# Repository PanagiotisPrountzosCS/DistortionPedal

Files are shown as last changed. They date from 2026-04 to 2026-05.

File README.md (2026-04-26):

# Custom distortion pedal implemented in kicad and ltspice

## This pedal is comprised of 3 stages:
  - Amplification
  - Clipping
  - Output Filtering

## The main branch contains a 100mm X 100mm PCB, while the 1590b-pcb branch contains a 35mm X 88mm PCB, which fits inside a 1590b box

## 1590b pcb


## 100mmx100mm pcb


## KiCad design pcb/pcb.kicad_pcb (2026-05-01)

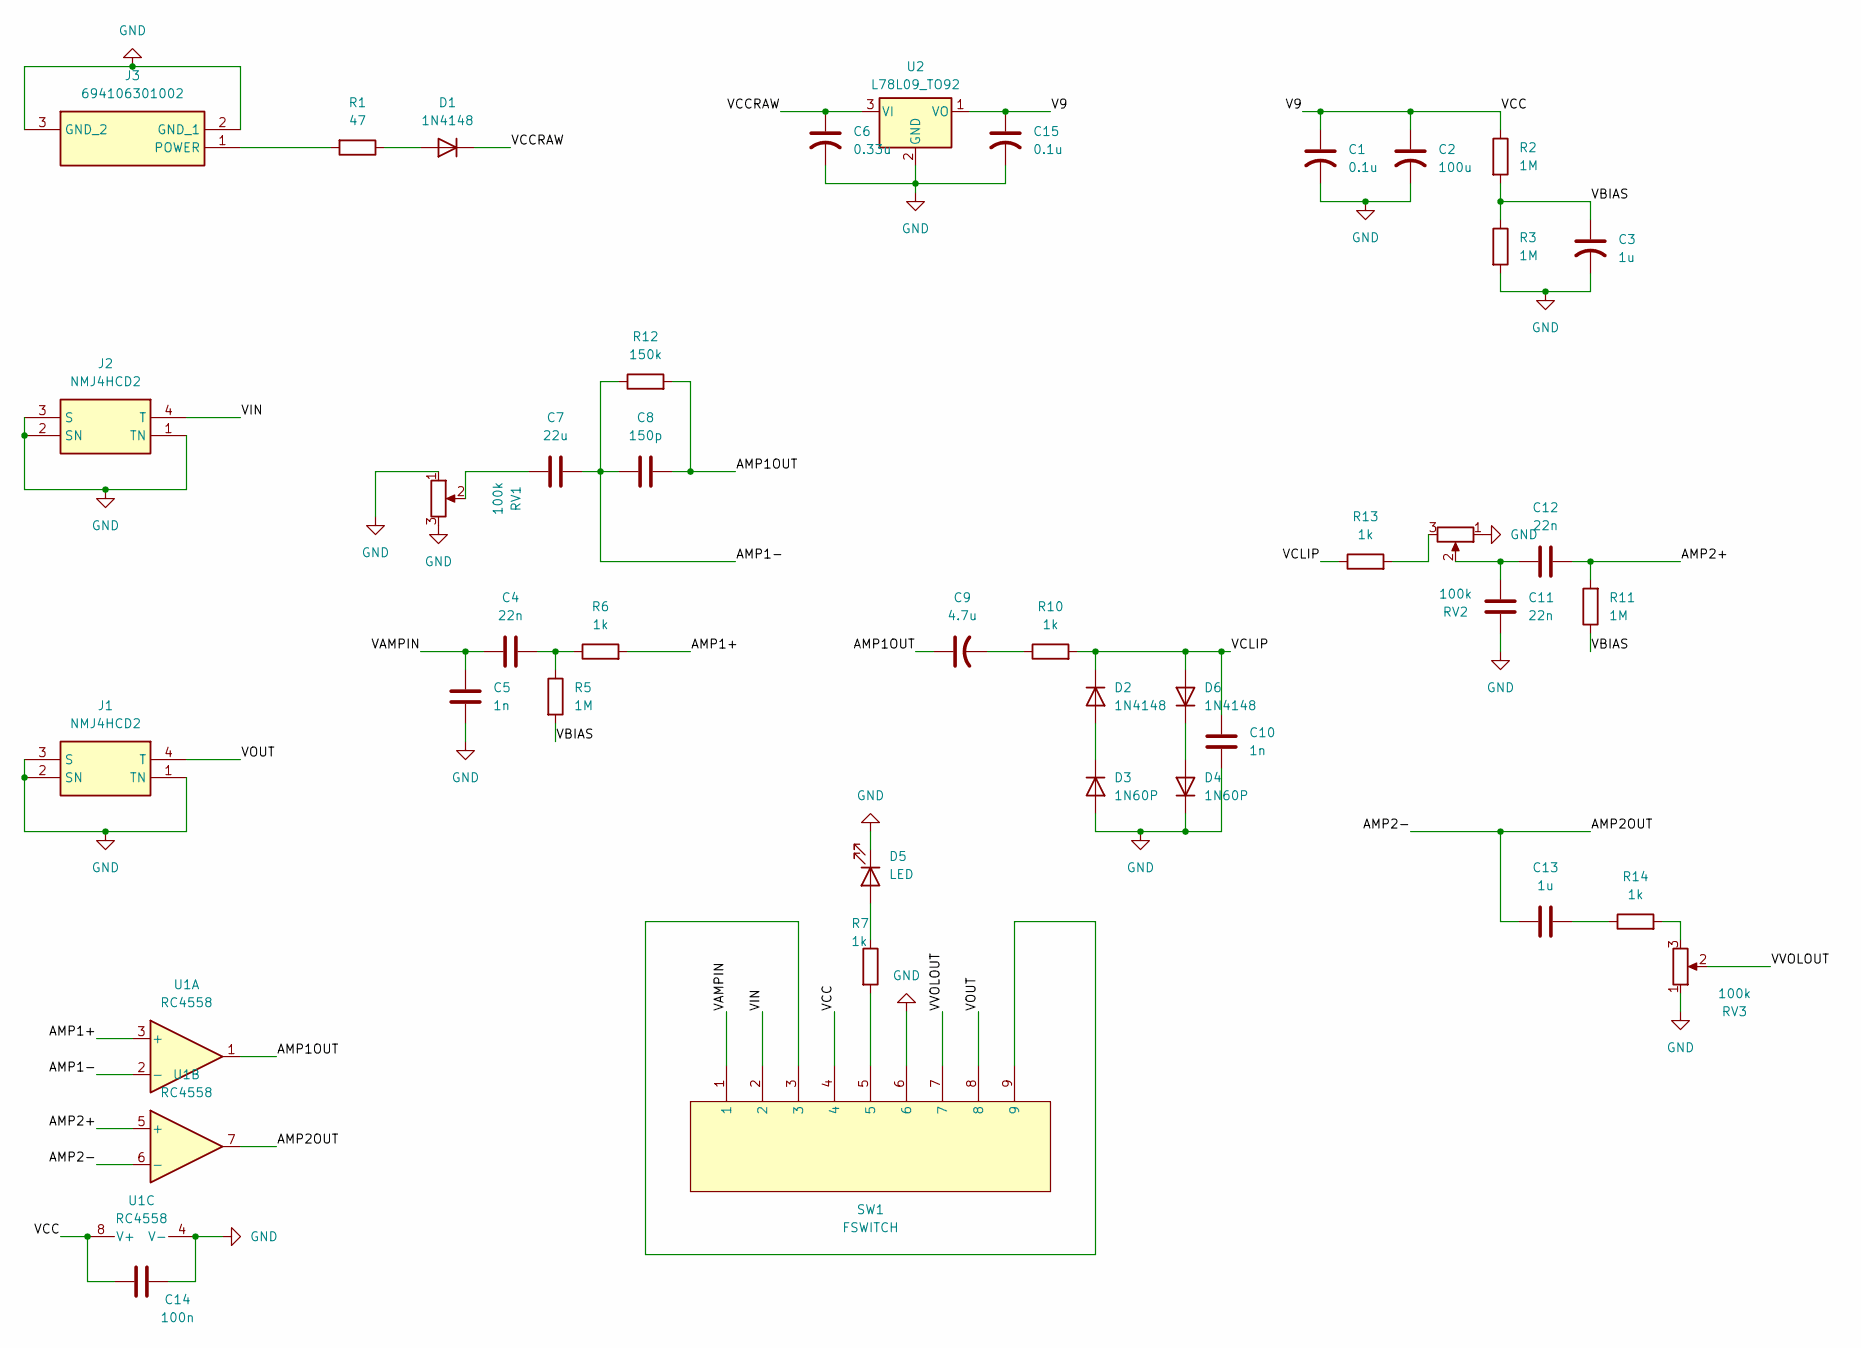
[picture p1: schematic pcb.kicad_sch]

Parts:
C1, C15: 0.1u; C_Radial_D5.0mm_H11.0mm_P2.00mm
C2: 100u; C_Radial_D6.3mm_H11.0mm_P2.50mm
C3: 1u; C_Radial_D6.3mm_H11.0mm_P2.50mm
C4, C12: 22n; C_Rect_L7.2mm_W2.5mm_P5.00mm
C5, C10: 1n; C_Disc_D3.0mm_W1.6mm_P2.50mm
C6: 0.33u; C_Radial_D5.0mm_H11.0mm_P2.00mm
C7: 22u; C_Radial_D5.0mm_H11.0mm_P2.00mm
C8: 150p; C_Disc_D3.0mm_W1.6mm_P2.50mm
C9: 4.7u; C_Radial_D5.0mm_H11.0mm_P2.00mm
C11: 22n; C_Disc_D3.0mm_W1.6mm_P2.50mm
C13: 1u; C_Rect_L7.2mm_W2.5mm_P5.00mm
C14: 100n; C_Disc_D3.0mm_W1.6mm_P2.50mm
D1, D2, D6: 1N4148; D_DO-35_SOD27_P7.62mm_Horizontal
D3, D4: 1N60P; D_DO-41_SOD81_P10.16mm_Horizontal
D5: LED; LED_D3.0mm
J1, J2: NMJ4HCD2; Mouser Part Number 550-12202
J3: 694106301002; Mouser Part Number 710-694106301002
R1: 47; R_Axial_DIN0207_L6.3mm_D2.5mm_P10.16mm_Horizontal
R2, R3, R5, R11: 1M; R_Axial_DIN0207_L6.3mm_D2.5mm_P10.16mm_Horizontal
R6, R7, R10, R13, R14: 1k; R_Axial_DIN0207_L6.3mm_D2.5mm_P10.16mm_Horizontal
R12: 150k; R_Axial_DIN0207_L6.3mm_D2.5mm_P10.16mm_Horizontal
RV1, RV2, RV3: 100k; Potentiometer_Omeg_PC16BU_Vertical
SW1: FSWITCH; 3PDT
U1: RC4558; CERDIP-8_W7.62mm_SideBrazed_LongPads_Socket
U2: L78L09_TO92; TO-92_Inline

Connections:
/AMP1+: R6.2, U1.3 (+)
/AMP1-: C7.2, C8.1, R12.1, U1.2 (-)
/AMP1OUT: C8.2, C9.1, R12.2, U1.1
/AMP2+: C12.2, R11.2, U1.5 (+)
/AMP2-: C13.1, U1.6 (-), U1.7
/V9: C1.1, C2.1, C14.2, C15.1, R2.1, SW1.4, U1.8 (V+), U2.1 (VO)
/VAMPIN: C4.1, C5.2, SW1.1
/VBIAS: C3.1, R2.2, R3.1, R5.2, R11.1
/VCCRAW: C6.1, D1.1 (K), U2.3 (VI)
/VCLIP: C10.2, D2.1 (K), D6.2 (A), R10.2, R13.1
/VIN: J2.4 (T), SW1.2
/VOUT: J1.4 (T), SW1.8
/VVOLOUT: RV3.2, SW1.7
GND: C1.2, C2.2, C3.2, C5.1, C6.2, C10.1, C11.2, C14.1, C15.2, D3.2 (A), D4.1 (K), D5.1 (K), J1.1 (TN), J1.2 (SN), J1.3 (S), J2.1 (TN), J2.2 (SN), J2.3 (S), J3.2 (GND_1), J3.3 (GND_2), R3.2, RV1.1, RV1.3, RV2.1, RV3.1, SW1.6, U1.4 (V-), U2.2 (GND)
unnamed: C4.2, R5.1, R6.1
unnamed: C7.1, RV1.2
unnamed: C9.2, R10.1
unnamed: C11.1, C12.1, RV2.2
unnamed: C13.2, R14.1
unnamed: D1.2 (A), R1.1
unnamed: D2.2 (A), D3.1 (K)
unnamed: D4.2 (A), D6.1 (K)
unnamed: D5.2 (A), R7.1
unnamed: J3.1 (POWER), R1.2
unnamed: R7.2, SW1.5
unnamed: R13.2, RV2.3
unnamed: R14.2, RV3.3
unnamed: SW1.3, SW1.9

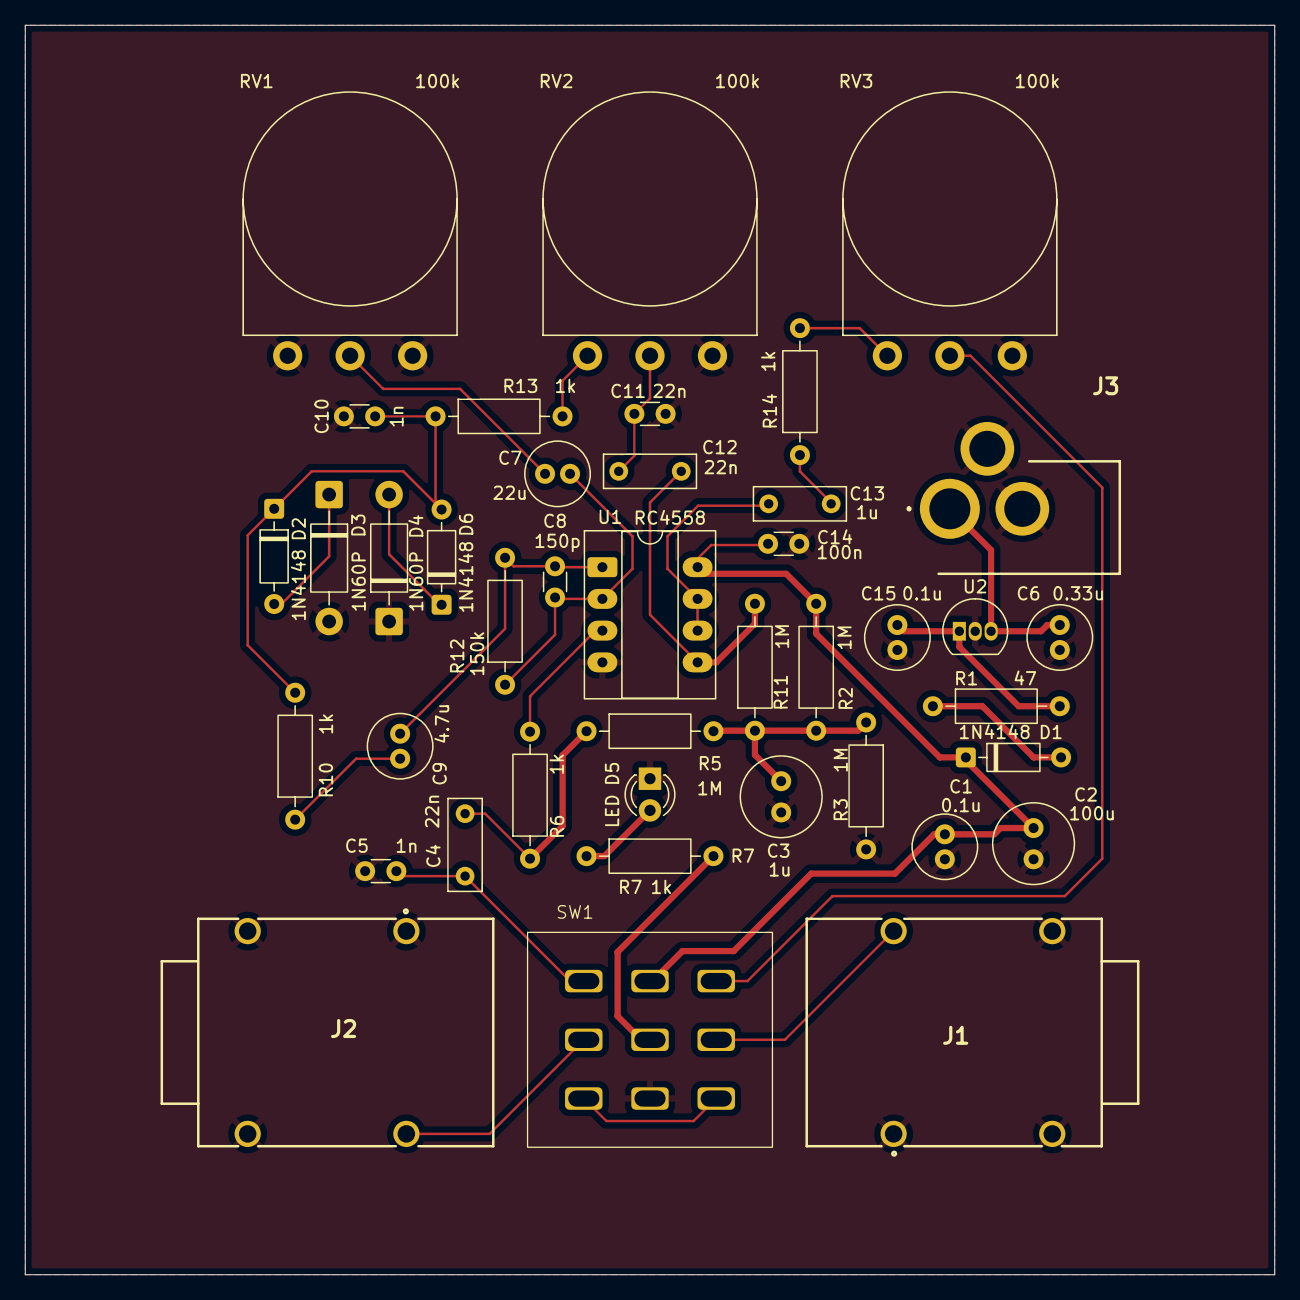
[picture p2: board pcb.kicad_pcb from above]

Board: 2 copper layers, 100.0 x 100.0 mm, 41 parts (0 on the bottom side), 28 nets.

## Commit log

2026-04-06 First commit - Circuit implementation
2026-04-07 Finalize schematic
2026-04-19 FIRST PCB COMMIT! :D
    [pcb.kicad_pcb, pcb.kicad_sch]
2026-04-19 add 3pdt footprint and symbol
    [pcb.kicad_pcb, pcb.kicad_sch]
2026-04-19 FIX LIBRARIES :O
    [pcb.kicad_pcb, pcb.kicad_sch]
2026-04-19 Finalize pcb
    [pcb.kicad_pcb, pcb.kicad_sch]
2026-04-23 Rework Amplifier Stage
    [pcb.kicad_pcb, pcb.kicad_sch]
2026-04-26 Add README with project overview and PCB information
    Added project description and PCB details for distortion pedal.
2026-04-26 Add new image to README for PCB visualization
    Added an additional image to the README for better visualization.
2026-05-01 Fix reverse polarity protection diode - schematic
    [pcb.kicad_pcb, pcb.kicad_sch]
